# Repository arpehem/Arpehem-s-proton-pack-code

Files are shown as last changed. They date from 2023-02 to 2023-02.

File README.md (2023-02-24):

# Arpehem-s-proton-pack-code
This is the code to use if you realyzed you bought a **common cathode bargraph** or only have access to this model.
This code is designed to be used with **2 Arduino nanos** or your favorite boards that have at least as many i/o ports and handles Arduino in order to minimyze the amount of wires running from the wand to the pack and has a unique smoke purge seuqence and design as well as all the bargraph animations.

These files and instructions are compatible with the Q-Pack.

Check out this link to see it in action:
https://youtu.be/VGt3vFmbnvs

Features:
- Common cathode bargraph full animations
- aRGB 4x5mm aRGB wand tip LED lights
- Functional top and front wand knobs
- Music mode and volume control on the wand
- Bargraph volume display
- Full pack aRGB controled
- New N-filter realistic smoke purge system
- DYI smoker build
- Compatible with pre-built smoker
- Uses DFplayer mini
- Customisable sound amplification
- Aviation connector adaptor for the wand handle
- Bluetooth (depending on the amp)

Upcomming updates:
- Firing tail sound 
- Game modes
- Top knob functionality

Which code to use?
- Use Neutrino wand code for the nano placed in the wand.
- Use Cyclotron_single_lights on your pack nano if you have single aRGB cyclotron lights.
- Use Cyclotron if you have 7 LED aRGB pucks for your cyclotron. Know that this code may be outdated, only single lights version is being worked on trough the end of this project as it was a design decision change but I wanted to include the option to use what you have/want and update the code yourself. (I was almost done I beleive and it is functional)

How it works:
Main power switch will turn on the slo-blo light at all time to indicate that the pack powered.
There is a sequence to turn the pack on that has to be respected. First step is to activate the particule accelerator controller (wand) on, flip on the wand light switch. That turns on the wand top light on indicating it's under tension. Second we flip the boot switch on which boots the pack and the rest of the wand. The pack goes trough it's boot animation sequence, the bargraph lights up by doing it's boot animation, then falls into it's loop at the same time as the pack starts and the 2 white hat lights on the wand start flashing. The third switch is to turn the smoke effect on and off as it is not allowed in all conventions.

Firing is fairly straight forward, just press the fire pin button. When firing, the 4 wand tip lights are controlled by a random function made to have white flashes, most of the time orange lights with hints of blues. The orange hat light also lights up when firing. At any time while firing, pressing the vent pin button will call a vent function that will pause the flashing light animation on the wand whyle the cyclotron is purging. If you installed a smoker, when you vent before entering the overhead sequence, there will be a breif lag (half a second) in between the command and the action to allow the smoker to build up a bit of smoke for a better effect. Shooting will make the cyclotron go faster untill it reaches the ovearheting sequence.

If you shoot long enough, you will enter the overheating sequence that will change the bargraph animation, sound the allarm, make the 3rd wand top light flash, flash all 4 cyclotron lights at the same time and alter LEDs on the Power cell. If you let go of the firing button or if you press the vent button in that 'mode', it will engage the vent sequence that will change the bargraph animation, light up the N-Filter, activate the purge fan propelling the smoke out of the N-filter and return to normal cycle loop afterwards.

If you keep shooting, you will enter the overheat sequence. The bargraph animation will change and the pack will force vent, doing all the thing normal venting would do but insttead of going back to the normal cycle sequence, it will force shutdown. This is by design. If this happens to you, you have to turn off both the boot and the wand pin switches and switch them back on in the propper order for it to restart. Only shutting down the pack switch on the wand will not allow to reboot, the user has to complete the shutdown sequence by turning everything off before turning it back on to exit the overheated mode.

Controlling the music and the volume is done with the front knob which is attached to the rotary encoder. Pressing it once will put it in volume mode which will display it's value on the bargraph. Raisin the volume will raise the bargraph value and vice versa. Clicking it once more will bring it back to normal mode. Double clicking the rotary encoder will start the music and holding it down will skipp to the next song. Clicking it twice again will bring it back in normal pack mode.

Required components:
-  Audio option 1 (speakers and sub watts have to be a bit more than the chosen amp output to avoid any problems):
- - 1 x Subwoofer the size that fits your motherboard speaker hole.
- - 2 x 3" car speaker 
- - 1 x amp with 2 speaker channels and 1 sub channel
- Audio option 2 (speaker wattage has to be a bit more than the chosen amp output to avoid any problems):
- - 1 x Speaker that fits your motherboard speaker hole.
- - 1 x amp 1 channel (mono)
- DIY Smoker:
- - 1 x 510 to EGO adapter (optional but way easier to use)
- - 1 x 12a 100W buck converter
- - 3 X 20a relay
- - 1 x 0.8 omh Vape tank and coil
- - 1 x 50mm 230mah blower fan
- - 3d printer
- - 3" of 1/4" plastic tubing that can be found in hardware stores
- - 3/16" A/C air conditioner filter sheet

Wand and pack:
- 1 x 2 way rotary switch (https://amzn.to/40L4XQX)
- 4 x 41x33mm Aluminum LED Flashlight Reflector Condenser Cup Cap
- 4 x 8mm aRGB LED (5mm could fit too)
- 1 x 6000 Mah battery pack (Recommend Talentcell)
- 3 x 20a relay
- 1 x 5V 40mm fan
- 2 x 3a buck converter
- 1 x 360 Degree Rotary Encoder Module
- 2 x Arduino nano (Or other boards with as many I/O ports that handles Arduino)
- 1 x Adafruit 16x8 LED Matrix Driver Backpack - HT16K33 Breakout
- 1 x Common cathode 28 segment LED bargraph
- 2 x Adafruit NeoPixel Stick for Arduino- 8 x WS2812
- 4 x 5mm aRGB LED
- 2 x 7mm Momentary (OFF-ON) Push Button Micro Switch
- 3 x 2 Position 3 Pins Mini Toggle Switch
- 1 x SS-10-23NP-L-E Rotary switch (https://bit.ly/3HUpoSU)
- 3 x 5mm white LED
- 1 x 3mm red LED
- 1 x 5mm yellow LED
- 1 x 5V white LED strip (about a foot)
- 10 x 1k omh resistances
- 2 x NPN transistor (2N2222)
- 1 x 4-PIN aviation connector (Optional)
- 1 x DF player mini

Here is a shopping list of the parts I found on Amazon:
https://www.amazon.ca/hz/wishlist/ls/2MNKQJ50DXHUB?ref_=wl_fv_le

Pinout:

Wand: 
- D2 Boot pin (wand switch 2)
- D3 Light switch (wand switch 1)
- D4 Smoke switch (wand switch 3)
- D5 Fire pin (fire button)
- D6 Vent pin (vent button)
- D7 Btn pin (Rotary encoder btn pin)
- D8 DT  (Rotary encoder data pin)
- D9 CLK  (Rotary encoder clock pin)
- D10 Cannon LED aRGB (Wand tip LED)
- D11 Fire light (wand tip orange light)
- D12
- D13 Rotary switch 1 (top knob rotary switch output 1)
- A0 Slo-blo LED (wand red light)
- A1 Wand white flashing hat light 1 (Wand top light large)
- A2 Wand white neon hat light (Wand top light small)
- A3 Wand white flashing hat light 2 (Wand top light large)
- A4 HT16K33 matrix SDA
- A5 HT16K33 matrix SCL
- A6 Rotary switch 2 (top knob rotary switch output 2)
- A7 Rotary switch 3 (top knob rotary switch output 3)

Pack:
- D2 Cyclotron aRGB data
- D3 Powercell aRGB data
- D4 Purge pin (Purge relay)
- D5 Smoke pin (smoke relay)
- D10 DFplayer mini RX
- D11 DFplayer mini TX

Instructions:
I will skipp trough: 'connect positive to the positive contact and negative to the negative contact. Remember that every negative needs to go to the main power switch before the power supply. Do not power devices trough the arduino 5V outputs, use buck converters to modulate the 12V signal to a 5V one. Audio needs to be on it's own buck converter to avoid interference BUT the amp, power that one 12V directly from the power source.

- **Wand connector:** Print the plug file. This is a replacement end cap for the wand handle allowing you to use a 4 pin aviation connector to easily disconnect the want from the pack.
- **Prepping the inputs:**
Every button or switch input need to go to the i/o ports it's assigned to which needs to have a 1k omh resistance running to the ground each. This is to limit interference and ghost inputs. (not a pun) An easy way to do this is to use dupont connectors in which you brace the input wire with the 1k omh resistor. Once everything connected, weld all resistances together on a ground.
- **Power and communication:** Start by running power from the main power switch (2 way rotary switch) connected to a buck converter that lowers the 12V to 5V to the 2 arduinos separately. Do not use 5V directly from the battery pack, it causes issues. Connect the first arduino's RX to the second one's TX and the first one's TX to the second one's RX. Basically, connect them backwards to one another. Now the wand 'speaks' to the pack.
- **Wand tip:**
Glue 4x5mm aRGB LEDs next to one another so that it fits where you want it to go in the barrel. Daisy chain them and connect the first one's data input to wand D10. (Remember, to connect individual aRGB LEDs, you need to connect i'ts data out to the next one's data in)
- **Power cell:**
Sawder the output contacts of the first bar onto the input contacts of the second one to make a 16 bit led bar. Connect the first bar data input to pack D3.
- **Cyclotron:**
Glue in the 8mm led INSIDE the flashlight reflector or trough them if you got 5mm aRGB LEDs instead. Connect the first one's data pin to pack D2.
- **DIY Smoker:**
We're going to push air in the vape's air inlet instead of pulling it out. Use a dremel to marry the blower fan to the side of the vape tank. Use a tie-wrap to secure the blower fan onto the base of the vape tank alligned with the vape tank's air intake. Dril a hole in your 510 to EGO adapter's base and use it to sawder in a wire to ground. Sawder directly onto the midle contact for the positive contact. Screw in the vape tank adaptor and connect it to the high power buck converter. Connect the high power buck converter to a 20a relay. That relay is controlled by the smoke pin Arduino output. The white 5v LED strip is to be connected to it's own relay and so does the 40mm purge fan. Theire individual relays are activated by a third relay that is driven by the smoke purge pin.

You will need to print these files for the purge tank:
https://www.thingiverse.com/thing:5848057

**You'll need these pieces:**
- 45_intake_2
- 90_angle
- Vent_cup
- 90_intake_2
- and a tip diffuser of your liking listed in the files.

You have an array of tips to choose, I prefer the 1 row 1 tip diffuser.
Print the smoker files.
Glue on the tip on the straight end of the 90_intake_2 piece. Glue the 45_intake_2 in the side hole of the vent_cup. Glue to 90_intake_2 to the end of the 45_intake_2 end in the vent_cup. Use 1/4" plastic tubing to connect the intake to the 90_angle and then to then output of the vape tank.
The parts are jointed by 1/4" plastic tubing.
Cut a piece of 3/16" air filter a bit larger than the 40mm fan. Place the air filter on the vaent cup round hole and crew the 40mm in with 4 M3 screws pushing trough the filter. This will create enough air resistance so that the smoke stays in the smoker but not enough to keep the fan from blowing air trough it. You're going to need to tweak the buck converter's voltage for your vape machine to produce a light but thick smoke that produces the wanted effect. You should now have a cup fitting to be glued inside the proton pack, alligned with the N-filter that has a fin on it's back and a tube driving the smoke from the smoker output to about halfway into the N-filter. **Glue down the assembly only after installing N-filter meshes and lights.** You will not be able to remove the N-filter purge container. If the purge fan is not spinning fast enough, change it's relay power supply to be on a different buck converter. It means that the N-filter lights are drawing too much power so you need a different power moduluator (buck in our instance). 
- **Bought smoker**:
Follow the smoker's instructions on how to power it but, do it trough the smoker relay so that it's activated by our code. There is no special need for the smoker in order for the purge function to work properlly other than to spew out smoke when powered.If the purge fan is not spinning fast enough, change it's relay power supply to be on a different buck converter. It means that the N-filter lights are drawing too much power so you need a different power moduluator (buck in our instance).
- **Connecting a relay to arduino:**
In order for the arduino to be able to drive a relay, we're going to need to use transistors attached to resistances. Sawder a 1k resistance to the middle prone of a PNP 2N2222 transistor. Sawder one of the 2 side ones to the negative of the power supply and the other end to the relay. Whatever is driven by the relay needs to be connected to the ground trough the relay and directly to the negative side of the power supply/main power switch. Connect the resistance that is sawdered onto the middle prone of the transistr to the Arduino board. Do this for the smoker pin and the purge pin relays. A relay has 2 emmiter prones, one normally opened, one normally closed, you want your signal to run trough the normally opened one. Normally opened mean that it does not normally convey signal, the circuit is opened (as in there's a break in the circuit) it needs an interraction to close the circuit and therefore transmit the signal/voltage.
- **Audio:**
Connect the speaker(s) to the amp. Power the amp straight from the powercell. Don't use power converters as it will induce interference in the audio signal. Connect the amp's ground the main power switch (or power if you decided to control power by the positive). Connect the DFplayer mini outputs to the amp's input. Unpack the MP3.rar in a folder called MP3 on a SD card and insert it in de DFplayer mini.
- **Front volume/music knob:**
Desawder the rotary encoder from it's board without damaging either parts. Use 1" wires sawdered to each leg of the rotary encoder and sawder those onto their respective places on the removed board. There you have it: a rotary encoder that fits in the front knob position. Carefull not to drill the hole it goes into too close to the Clippard valve as the front knob will need to have clearance to be pushed and turned. In order to glue the front knob on the rotary encoder correctly, I recommend using a gauge to space it from the main wand box when installing to leave clearance for a click and if you are using an alluminum knob, I used a long set screw from the inside of it to create an inner spacer.
- **Top knob:**
Glue a M3 nut on the top the 3 position rotary switch selector. Run a long M3 screw in the tob knob and glue them together. Install top knob in it's place and screw in the nut on the top of the rotary switch to it. Now that the top knob is attached to the rotary switch, make sure the know is in the correct place and glue the 3 position switch to the inside of the wand box. You can unscrew and screw it back (for painting) if you are carefull. Make sure to not apply too much force to the switch when screwing the top knob in and out as it will easily break (I recommend ordering 5 to have spares).
- **Main power switch (optional):**
Dril a hole where the crank generator crank goes. Use the 2 way oven style switch and glue it inside the pack trough the hole so that you can fit/glue the crank on it's stub. Use this switch between every ground and the power source ground.

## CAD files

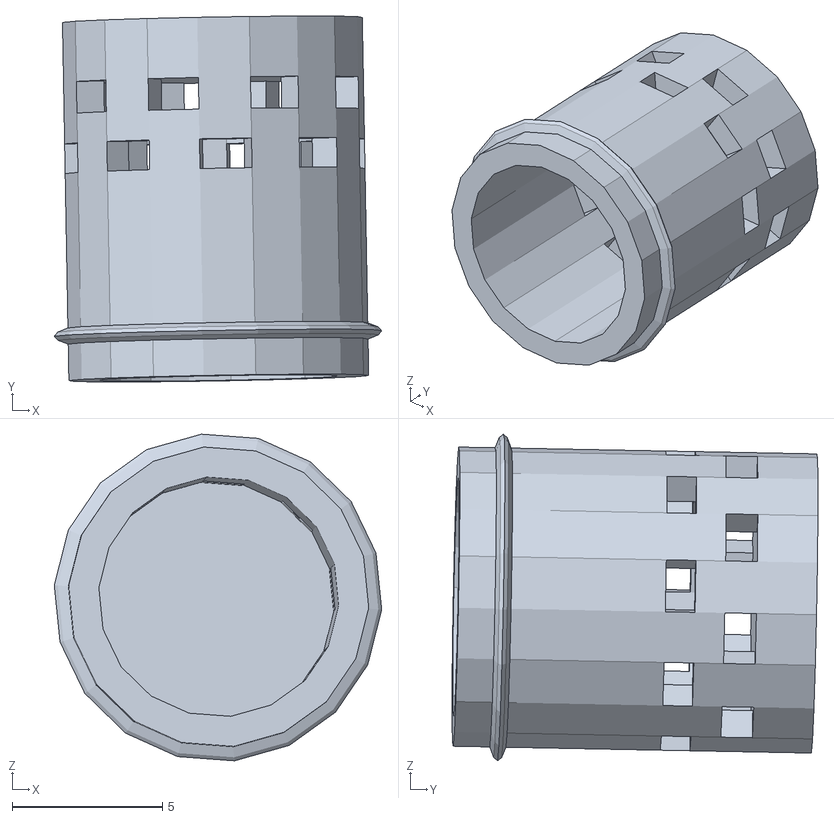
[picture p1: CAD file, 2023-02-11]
2 row.stl
10.9 x 12.2 x 10.9

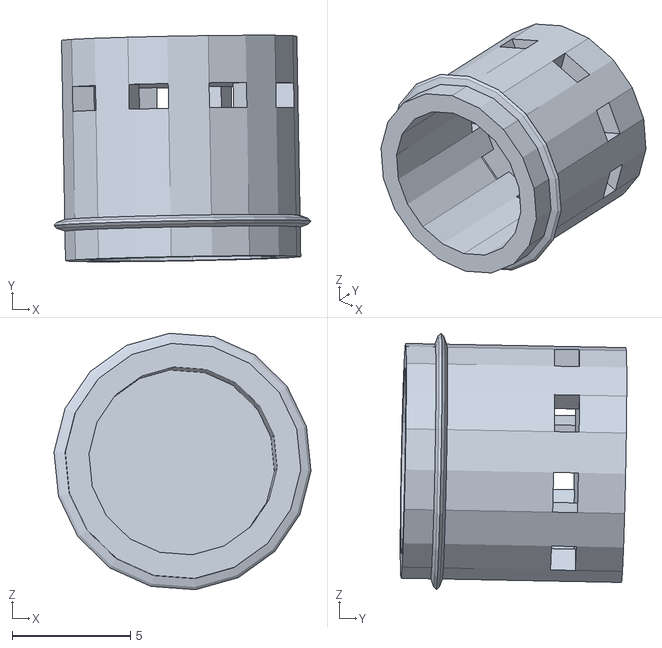
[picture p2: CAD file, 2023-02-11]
1 row.stl
10.9 x 9.60 x 10.9

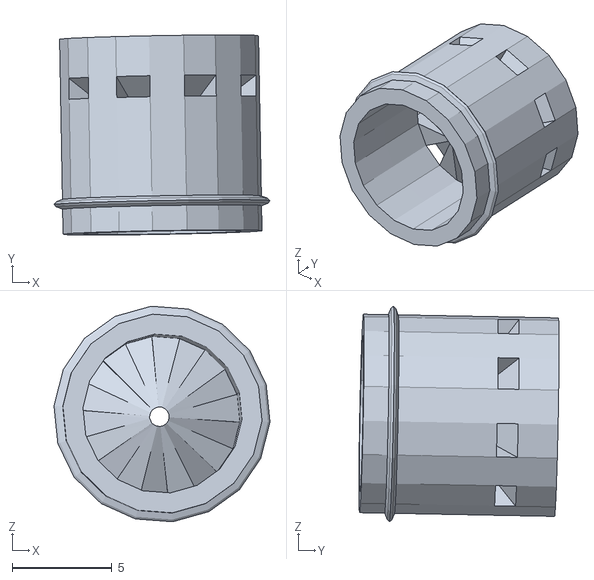
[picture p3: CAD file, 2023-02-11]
1 row 1 spray1.stl
10.8 x 10.0 x 10.8

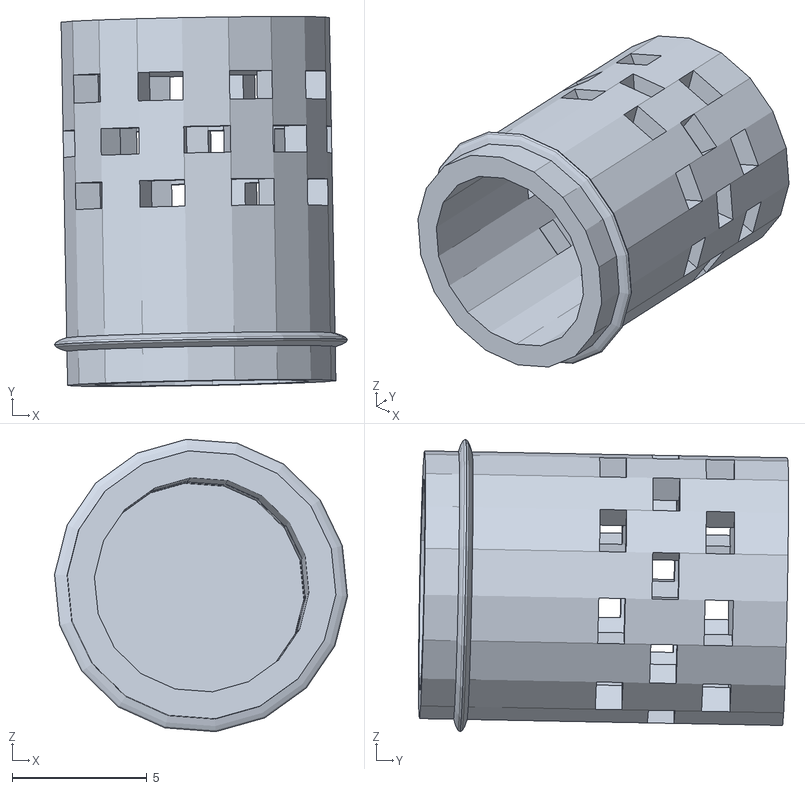
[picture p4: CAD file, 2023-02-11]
3 row.stl
10.9 x 13.8 x 10.9

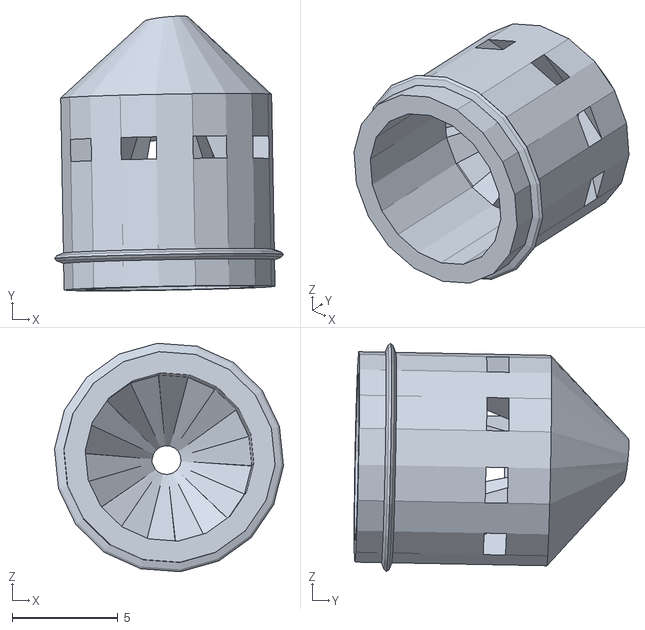
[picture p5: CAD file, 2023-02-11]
1 row 1 tip.stl
10.8 x 13.0 x 10.8

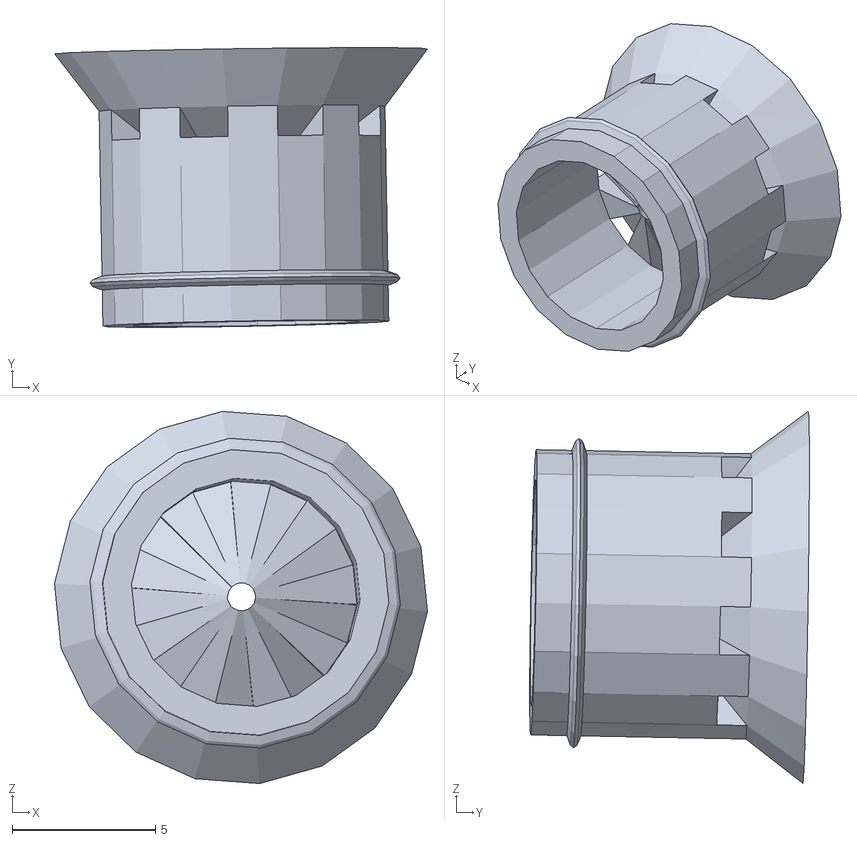
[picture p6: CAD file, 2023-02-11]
1 row 1 spray3.stl
13.0 x 9.75 x 13.0

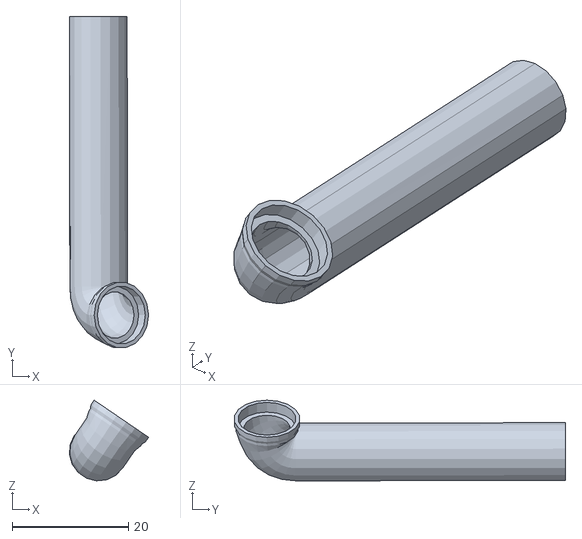
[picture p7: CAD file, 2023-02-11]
90 intake2.stl
13.6 x 57.0 x 13.9

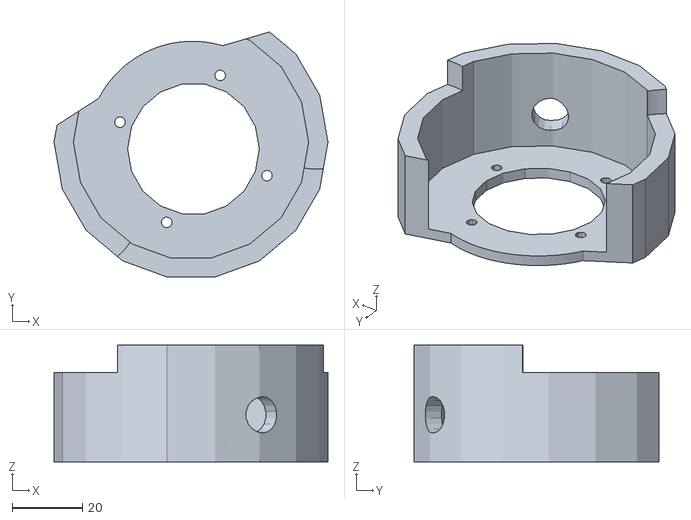
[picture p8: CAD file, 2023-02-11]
Vent_cup.stl
77.8 x 69.6 x 33.2

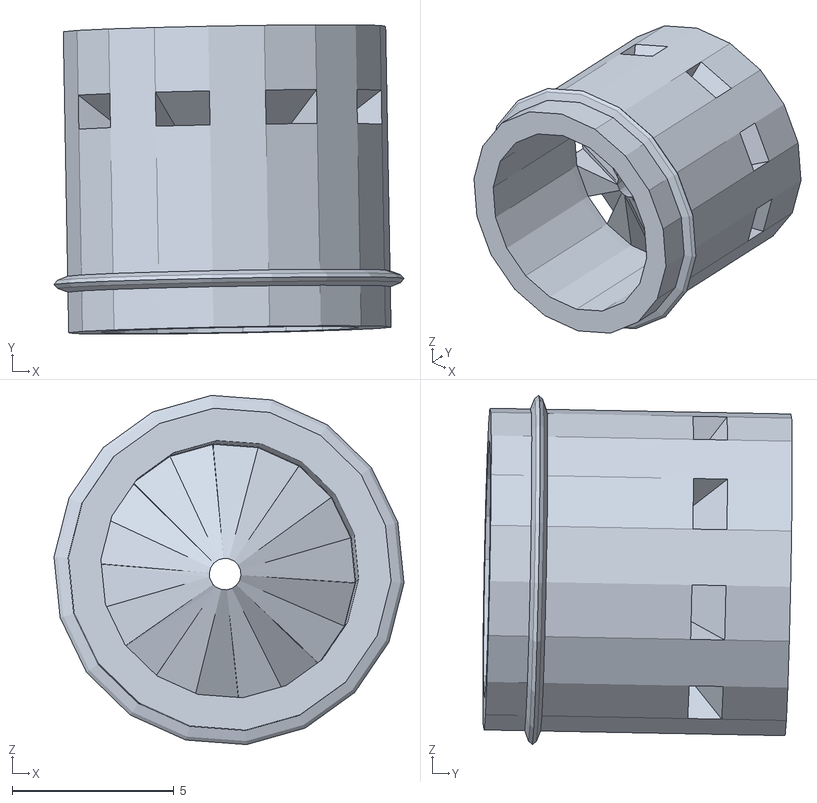
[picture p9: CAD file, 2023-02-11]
1 row 1 spray2.stl
10.8 x 9.57 x 10.8

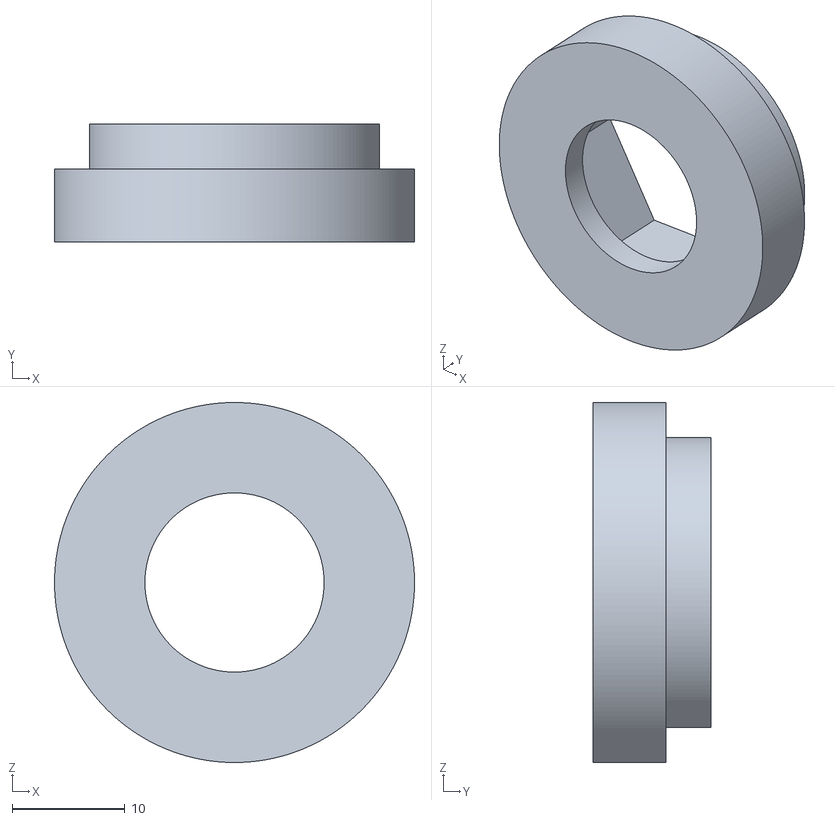
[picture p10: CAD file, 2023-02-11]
plug01.stl
32.0 x 10.5 x 32.0

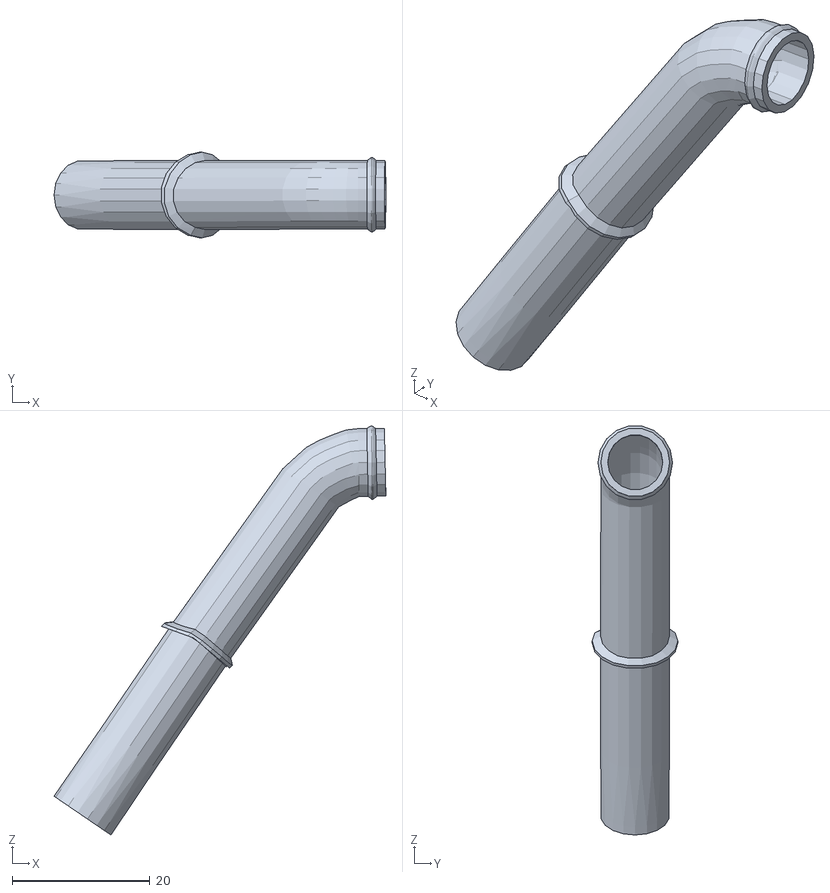
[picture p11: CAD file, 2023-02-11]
45 intake2.stl
48.2 x 12.5 x 59.4

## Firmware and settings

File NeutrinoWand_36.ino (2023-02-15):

// This code has initially been created entirelly by Arpehem and is free to be used, modified or updated by anyone as long as this credit remains.
// This code is compatible with a common cathode bargraph only.

#include <FireTimer.h>
#include <DFPlayerMini_Fast.h>
#include <SoftwareSerial.h>
#include <BfButton.h>
#include <BfButtonManager.h>
#include <HT16K33.h>
#include <FastLED.h>
# define NUM_LEDS 4
# define NUM_STRIPS 1
# define WAND_LEDS 4
#define WAND_LED_PIN 10

HT16K33 matrix = HT16K33();
char Volume=20;
int bargraph=0;
int BGadress[4]={1,4,8,2};
int demo;
char S = 35;
int i;
int overloadtime=5000;
int J=0;
int K=0;
int shooting = 0;
enum currentstate{on,off,boot,cycle,fire,overloading,overload,overheat,music,volumep,ventp}state;
unsigned long myWandTime;
unsigned long previousWandTime = 0;
unsigned long previousLightTime=0;
unsigned long previousAlarmTime=0;
unsigned long previousShootLight=0;
unsigned long ShootingTime = 0;
unsigned long PreviousShootingTime = 0;
bool isFire = false;
bool wasFire =false;
bool booted=false;
bool issmoke=false;
bool up = true;
bool lightcycle =true;
bool alarmlighton =false;
int firepin = 5;
int bootpin = 2;
int ventpin = 6;
int smokeswitch = 4;
int lightswitch =3;
int rot1 = 13;
int firelight = 11;
int powerlight = 12;


CRGB wand_leds[WAND_LEDS];
CLEDController *controllers[NUM_STRIPS];


int btnPin=7;
int DT=8;
int CLK=9;
BfButton btn(BfButton::STANDALONE_DIGITAL,btnPin,true,LOW);

int counter = 0;
int angle = 0;
int aState;
int aLastState;

void pressHandler (BfButton *btn, BfButton::press_pattern_t pattern){  //////////////////////////////////ROT Handler///////////////////////////////////////
  switch (pattern) {
    case BfButton::SINGLE_PRESS:
   // myMP3.playAdvertisement(8);
    if (state==volumep){
      state=cycle;
     Serial.write('c');
      delay(50);
    }
    else{
      Serial.write('V');
     delay(50);
      state=volumep;
          matrix.clear();
    i=Volume;
    angle=Volume;
    counter=Volume;
    cycle_switch();
  matrix.write();
    }
      break;
      
    case BfButton::DOUBLE_PRESS:
   // myMP3.playAdvertisement(8); 
         if (state==music){
      state=cycle;
Serial.write('m');
delay(50);
    }
    else{
      state=music;
Serial.write('m');
delay(50);
    }
      break;
      
    case BfButton::LONG_PRESS:
    Serial.write('n');
delay(50);
    
      break;
  }
}




void setup() {       ///////////////////////////SETUP///////////////////////////////////
Serial.begin(9600);
//mySerial.begin(9600);
//myMP3.begin(mySerial, true);
pinMode(CLK, INPUT_PULLUP);
pinMode(DT, INPUT_PULLUP);
aLastState = digitalRead(CLK);
//myMP3.volume(Volume);
  //Button settings
  btn.onPress(pressHandler)
  .onDoublePress(pressHandler) // default timeout
  .onPressFor(pressHandler, 1000); // custom timeout for 1 second

  matrix.init(0x70);   // start the matrix on I2C address 0x70
  delay(1500);
state= off;
pinMode(firepin, INPUT);
pinMode(bootpin, INPUT);
pinMode(ventpin, INPUT);
pinMode(smokeswitch, INPUT);
pinMode (lightswitch, INPUT);
pinMode (rot1, INPUT);
pinMode (11, OUTPUT);
pinMode (12, OUTPUT);
//analog i/o
pinMode (A0, OUTPUT);
pinMode (A1, OUTPUT);
pinMode (A2, OUTPUT);
pinMode (A3, OUTPUT);
pinMode (A6, INPUT);
pinMode (A7, INPUT);

controllers[0] = &FastLED.addLeds<WS2812, WAND_LED_PIN, RGB>(wand_leds, WAND_LEDS); // Assign wand LED to controller 0
  FastLED.setMaxPowerInVoltsAndMilliamps(5,500);

analogWrite(A0, 175); // light slo-blo as pack status light
FastLED.setBrightness(255);
FastLED.clear();
FastLED.show(); 
}
void loop() {                  //////////////////////////////////////LOOP//////////////////////////////////////

myWandTime=millis();  // Records current time

if (myWandTime>previousShootLight+25&&isFire==true){
  shooting++;
  if (shooting>3){
    shooting=0;
  }
     FastLED.clear();
//wand_leds[min(shooting+1,3)] = CRGB(150,30,255);
wand_leds[random(0,3)] = CRGB(75,30,255);
wand_leds[random(0,3)] = CRGB(200,30,30);
wand_leds[random(0,3)] = CRGB(150,30,0);
wand_leds[random(0,3)] = CRGB(150,30,0);
wand_leds[random(0,3)] = CRGB(150,30,0);
wand_leds[max(shooting-1,0)] = CRGB(150,30,0);
wand_leds[shooting] = CRGB(254,100,0);
  FastLED.show(); 
  previousShootLight=millis();
}
if (digitalRead(smokeswitch)==true&&issmoke==false){
Serial.write('y');
issmoke=true;
}
if (digitalRead(smokeswitch)==false&&issmoke==true){
Serial.write('x');
issmoke=false;
}
if (digitalRead(lightswitch)==true&&state==off&&digitalRead(bootpin)==false){
state=on;
analogWrite(A7,130);
}
if (digitalRead(lightswitch)==false&&state!=off){
state=off;

}
if(state==off||state==overload){
analogWrite(A1,0);
analogWrite(A2,0);
analogWrite(A3,0);
analogWrite(A6,0);
analogWrite(A7,0);
}


if(myWandTime>previousLightTime+600&&digitalRead(lightswitch)==true&&lightcycle==false&&booted==true){
  analogWrite(A1,130);
  analogWrite(A3,0);
  lightcycle=true;
  previousLightTime=millis();
}
if(myWandTime>previousLightTime+600&&digitalRead(lightswitch)==true&&lightcycle==true&&booted==true){
  analogWrite(A3,130);
  analogWrite(A1,0);
  lightcycle=false;
  previousLightTime=millis();
}

  btn.read();
  
  aState = digitalRead(CLK);

                                  //////////////////////////Encoder rotation tracking////////////////////////////////
  if (aState != aLastState){     
     if (digitalRead(DT) != aState) { 
       counter ++;
       angle ++;
      //        counter=min(counter,29);
     //  angle=min(angle,29);
       
     }
     else {
       counter--;
       angle --;
      // counter=max(counter,0);
      // angle=max(angle,0);
     }
     if (counter >=28 ) {
       counter =28;
     }
     if (counter <=-0 ) {
       counter =-0;
     }
    // Serial.println(counter); 
  }   
  aLastState = aState;
if (state==volumep&&Volume!=counter){
    matrix.clear();
    Volume=counter;
    Volume=min(Volume,28);
    Volume=max(Volume,0);
    i=Volume;
    Serial.write(Volume);
    cycle_switch();
  matrix.write();
  
 // myMP3.volume(Volume); 
 // delay(50);
 //   Serial.begin(9600);
}
  
if(digitalRead(ventpin)==true&&state==fire||digitalRead(ventpin)==true&&state==overheat||digitalRead(ventpin)==true&&state==overloading){ ///////////////////////////// if pack is shooting and the vent pin is pressed before the forced venting, calls venting without shuting down/////////////////////////////
  vent();
  state=cycle;
  Serial.write('c');
  delay(50);
  loopsound(2);
  i=0;
  J=0;
  S=35;
  Serial.write(S);
}

if(state!=off&&state!=on&&state!=cycle&&state!=overload&&state!=overloading&&state!=overheat&&state!=music&&state!=volumep&&state!=boot&&isFire==false){
  state=cycle;
    Serial.write('c');
  delay(50);
  S=35;
  Serial.write(S);
 }
if(state==music && myWandTime > previousWandTime+35){
  cyclesequence();
}
if(state==overloading&&isFire==false||state==overheat&&isFire==false){
  vent();
  state=cycle;
    Serial.write('c');
  delay(50);
  S=35;
  Serial.write(S);
}

//if(digitalRead(bootpin)==false){ //if switch is off, state is off
//  state=off;

//}
isFire=digitalRead(firepin); // Reads fire button input and sets isFire accordignly
//if(state==off){
//  isFire=false;
//}

if(state!=boot&&state!=on&&digitalRead(bootpin)==false&&booted==true){ ///////////////////////////////////// if state is not boot state, pack is booted and switch is off, calls shutdown////////////////////////////////////
  state=off;
Serial.write("f");
delay(50);
shutdownsequence();
  
  booted=false;
  state=off;
  matrix.clear();
  matrix.write();
  i=0;
}
if(state==on&&digitalRead(bootpin)==true&&booted==false){ //////////////////////////////////// if pack is not booted and switch is on, calls boot//////////////////////////////////////
  state=boot;
  Serial.write("b");
delay(50);
}
if(state==off&&digitalRead(bootpin)==true&&booted==true){ /////////////////////////////////////// if pack is off but still booted and switch is on, calls shutdown/////////////////////////////////
  state=off;
 // shutdownoverloadsequence();
 shutdownsequence();
Serial.write("f");
delay(50);
}

  if(state==boot){  /////////////////////////////// Check for boot state and calls bootsequence/////////////////////////////////////////////////

  playsound(1);
  bootsequence();
  
  }
if (myWandTime > previousAlarmTime+200&&state==overloading||myWandTime > previousAlarmTime+200&&state==overheat){ // Check for cycle , calls cyclesequence
  alarmlight();
}
if (myWandTime > previousWandTime+28 && isFire == false && booted == true&&state==cycle){ // Check for cycle , calls cyclesequence
  cyclesequence();
}
if (myWandTime > previousWandTime+S && isFire == true && booted == true&&S>1){ // Check for fire , calls firesequence
firesequence();
}
if (myWandTime > previousWandTime+35 && isFire == true && booted == true&&S==1&&J<300 && state != off && state != overload&&state!=ventp){ // Check for fire , calls overheat sequence


  cycleoverheatsequence();
}
if (myWandTime > previousWandTime+35 && isFire == true && booted == true&&state!=ventp&&S==1&&J==300&&K<125&& state != off){ // Check for fire , calls overload/vent sequence


  overloadsequence();
}
}
void demo_cycle (){            //////////////////////////////// Demo of bargraph animations without timing or trigger//////////////////////////////////////////////
    demo++;
  for (int i=0; i<2;i++){
    cyclesequence();
  }   
    for (int i=0; i<10;i++){
    firesequence();
  } 
    for (int i=0; i<20;i++){
    cycleoverheatsequence();
  }  
  overloadsequence();

}
void alarmlight(){
  switch (alarmlighton) {
  case true:
        analogWrite(A2, 0);
    alarmlighton=false;
    previousAlarmTime=millis();  
    break;
  case false:
    analogWrite(A2, 130);
    alarmlighton=true;
    previousAlarmTime=millis();  
    break;
  default:
    // statements
    break;

}
}
void playsound(int sound){
//    mySerial.begin(9600);
 // delay(50);
 // myMP3.play(sound); 
 // delay(50);
 //   Serial.begin(9600);
 
}
void loopsound(int sound){
 //   mySerial.begin(9600);
//  delay(50);
//  myMP3.loop(sound); 
//  delay(50);
//    Serial.begin(9600);
  
}
void bootsequence(){  // Boot Sequence
  for(int i=0&&Serial.write("b");i<28;i++){
    matrix.clear();
    cycle_boot(i);
    matrix.write();
    delay(125);
    }
  for(int i=28;i<57;i++){
    matrix.clear();
    cycle_boot(i);
    matrix.write();
    delay(25);
  }
  booted=true;
  loopsound(2);
  state=cycle;
      Serial.write('c');
    delay(50);
  }
void shutdownsequence(){ 
  Serial.write("f");
  
  playsound(10);
  analogWrite(A1,0);
  analogWrite(A3,0);
  for(int i=28;i<57;i++){
    matrix.clear();
    cycle_boot(i);
    matrix.write();
    delay(75);
  }
  state=off;
  digitalWrite(firelight,LOW);
  
  delay(50);
  booted=false;
  matrix.clear();
  matrix.write();
  i=0;
  previousWandTime=myWandTime;
  
}
void shutdownoverloadsequence(){  
Serial.write("f");
playsound(10);  
    for(int i=28;i<57;i++){
    matrix.clear();
    cycle_boot(i);
    matrix.write();
    delay(25);
  }
  state=overload;
  
 
  delay(50);
  booted=false;
  i=0;
  matrix.clear();
  matrix.write();
  
  
  previousWandTime=myWandTime;
}
void cyclesequence(){  // Normal cycle sequence
    if(wasFire==true){
    wasFire=false;
    FastLED.clear();
    FastLED.show(); 
    i=0;
    state=cycle;
    S=35;
    Serial.write(S);
    Serial.write('c');
    delay(50);
    digitalWrite(firelight,LOW);
    analogWrite(A2,0);
  }
  if(state!=cycle&&state!=music&&state!=volumep){
    loopsound(2);
    state=cycle;
        Serial.write('c');
    delay(50);
    
    
  }
  if (i>28){
    i=28;
  }
  if (i==28){
    up=false;
  }
  if (i==0){
    up=true;
  }
  if(up == true){
    i++;
  }
    if(up==false){
    i--;
  }
matrix.clear();
cycle_switch();
matrix.write();
previousWandTime=myWandTime;
}
void firesequence(){  // Fire suquence
  if (wasFire==false){
  wasFire=true;
  Serial.write('s');
  delay(50);
  loopsound(11);
digitalWrite(firelight,HIGH);
 }

 if (state!=fire){
    i=0;
  state=fire;
  J=0;
 }
 ShootingTime=millis();
if(ShootingTime>PreviousShootingTime+500){
  S--;
  PreviousShootingTime=millis();
Serial.write(S);

}
 if (i>19){
   i=0;
  }
  i++;
matrix.clear();
fire_switch();
matrix.write();
previousWandTime=myWandTime;
}
void vent(){
  state=ventp;
  FastLED.clear(); 
  FastLED.show(); 
  analogWrite(A2,0);
       Serial.write('v');
       digitalWrite(firelight,LOW);
    delay(50);
  playsound(9);
  wasFire=false;
  for (int i=24; i<34;i++){
  matrix.clear();
cycle_overload(i);
matrix.write();
delay(35);
}


matrix.clear();
cycle_overload(35);
matrix.write();
delay(3000);
state=off;
i=0;
previousWandTime=myWandTime;
}

void overloadsequence(){ // Overheat/vent sequence
 if(state==overheat){
  state=overloading;
 i=0;
 K=0;
 up=true;
     Serial.write('o');
    delay(50);
 }
K++;

   switch (K) {
  case 1:
    up=true;
    break;
  case 35:
    up=false;
    break;
  case 45:
    up=true;
    break;
  case 55:
    up=false;
    break;
  case 65:
    up=true;
    break;
  case 75:
    up=false;
    break;
  case 85:
    up=true;
    break;
  case 95:
    up=false;
    break;
  case 105:
    up=true;
    break;
  case 115:
    up=false;
    break;
  case 124:
  vent();
  analogWrite(A1,0);
analogWrite(A2,0);
analogWrite(A3,0);
analogWrite(A6,0);
analogWrite(A7,0);
shutdownsequence();
state=overload;
isFire=false;
wasFire=false;

      break;
}
   
if(up==true){
  i++;
}
if(up==false){
  i--;
}
if(K<124){
    matrix.clear();
cycle_overload(i);
matrix.write();
previousWandTime=myWandTime;

}
if(K==124){
  i=0;
  J=0;
  K=0;
  S=35;
  Serial.write(S);
}
}
void cycleoverheatsequence(){ // Overload (warning) sequence
   if(state==fire){
  state=overheat;
  i=0;
//J=0;
loopsound(16);
     Serial.write('h');
    delay(50);
 }
i++;
J++;
  matrix.clear();
  cycle_overheat();
  matrix.write();

if (i>4){
  i=0;
}
previousWandTime=myWandTime;
}
void cycle_boot(int boot){
  switch (boot) {
  case 1:
    matrix.setRow(6, 2);
    break;
  case 2:
    matrix.setRow(6, 10);
    break;
  case 3:
    matrix.setRow(6, 14);
    break;
  case 4:
    matrix.setRow(6, 15);
    break;
  case 5:
    matrix.setRow(5, 2);
    matrix.setRow(6, 15);
    break;
  case 6:
    matrix.setRow(5, 10);
    matrix.setRow(6, 15);
    break;
  case 7:
    matrix.setRow(5, 14);
    matrix.setRow(6, 15);
    break;
  case 8:
    matrix.setRow(5, 15);
    matrix.setRow(6, 15);
    break;
  case 9:
    matrix.setRow(4, 2);
    matrix.setRow(5, 15);
    matrix.setRow(6, 15);
    break;
  case 10:
    matrix.setRow(4, 10);
    matrix.setRow(5, 15);
    matrix.setRow(6, 15);
    break;
  case 11:
    matrix.setRow(4, 14);
    matrix.setRow(5, 15);
    matrix.setRow(6, 15);
    break;
  case 12:
    matrix.setRow(4, 15);
    matrix.setRow(5, 15);
    matrix.setRow(6, 15);
    break;
  case 13:
    matrix.setRow(3, 2);
    matrix.setRow(4, 15);
    matrix.setRow(5, 15);
    matrix.setRow(6, 15);
    break;
  case 14:
    matrix.setRow(3, 10);
    matrix.setRow(4, 15);
    matrix.setRow(5, 15);
    matrix.setRow(6, 15);
    break;
  case 15:
    matrix.setRow(3, 14);
    matrix.setRow(4, 15);
    matrix.setRow(5, 15);
    matrix.setRow(6, 15);
    break;
  case 16:
    matrix.setRow(3, 15);
    matrix.setRow(4, 15);
    matrix.setRow(5, 15);
    matrix.setRow(6, 15);
    break;
  case 17:
        matrix.setRow(2, 2);
    matrix.setRow(3, 15);
    matrix.setRow(4, 15);
    matrix.setRow(5, 15);
    matrix.setRow(6, 15);
    break;
  case 18:
        matrix.setRow(2, 10);
    matrix.setRow(3, 15);
    matrix.setRow(4, 15);
    matrix.setRow(5, 15);
    matrix.setRow(6, 15);
    break;
  case 19:
        matrix.setRow(2, 14);
    matrix.setRow(3, 15);
    matrix.setRow(4, 15);
    matrix.setRow(5, 15);
    matrix.setRow(6, 15);
    break;
  case 20:
    matrix.setRow(2, 15);
    matrix.setRow(3, 15);
    matrix.setRow(4, 15);
    matrix.setRow(5, 15);
    matrix.setRow(6, 15);
    break;
  case 21:
    matrix.setRow(1, 2);
    matrix.setRow(2, 15);
    matrix.setRow(3, 15);
    matrix.setRow(4, 15);
    matrix.setRow(5, 15);
    matrix.setRow(6, 15);
    break;
  case 22:
    matrix.setRow(1, 10);
    matrix.setRow(2, 15);
    matrix.setRow(3, 15);
    matrix.setRow(4, 15);
    matrix.setRow(5, 15);
    matrix.setRow(6, 15);
    break;
  case 23:
    matrix.setRow(1, 14);
    matrix.setRow(2, 15);
    matrix.setRow(3, 15);
    matrix.setRow(4, 15);
    matrix.setRow(5, 15);
    matrix.setRow(6, 15);
    break;
  case 24:
    matrix.setRow(1, 15);
    matrix.setRow(2, 15);
    matrix.setRow(3, 15);
    matrix.setRow(4, 15);
    matrix.setRow(5, 15);
    matrix.setRow(6, 15);
    break;
  case 25:
    matrix.setRow(0, 2);
    matrix.setRow(1, 15);
    matrix.setRow(2, 15);
    matrix.setRow(3, 15);
    matrix.setRow(4, 15);
    matrix.setRow(5, 15);
    matrix.setRow(6, 15);
    break;
  case 26:
    matrix.setRow(0, 10);
    matrix.setRow(1, 15);
    matrix.setRow(2, 15);
    matrix.setRow(3, 15);
    matrix.setRow(4, 15);
    matrix.setRow(5, 15);
    matrix.setRow(6, 15);
    break;
  case 27:
    matrix.setRow(0, 14);
    matrix.setRow(1, 15);
    matrix.setRow(2, 15);
    matrix.setRow(3, 15);
    matrix.setRow(4, 15);
    matrix.setRow(5, 15);
    matrix.setRow(6, 15);
    break;
  case 28:
    matrix.setRow(0, 15);
    matrix.setRow(1, 15);
    matrix.setRow(2, 15);
    matrix.setRow(3, 15);
    matrix.setRow(4, 15);
    matrix.setRow(5, 15);
    matrix.setRow(6, 15);
    break;
  case 29:
    matrix.setRow(0, 15);
    matrix.setRow(1, 15);
    matrix.setRow(2, 15);
    matrix.setRow(3, 15);
    matrix.setRow(4, 15);
    matrix.setRow(5, 15);
    matrix.setRow(6, 13);
    break;
  case 30:
    matrix.setRow(0, 15);
    matrix.setRow(1, 15);
    matrix.setRow(2, 15);
    matrix.setRow(3, 15);
    matrix.setRow(4, 15);
    matrix.setRow(5, 15);
    matrix.setRow(6, 5);
    break;
  case 31:
    matrix.setRow(0, 15);
    matrix.setRow(1, 15);
    matrix.setRow(2, 15);
    matrix.setRow(3, 15);
    matrix.setRow(4, 15);
    matrix.setRow(5, 15);
    matrix.setRow(6, 1);
    break;
    case 32:
    matrix.setRow(0, 15);
    matrix.setRow(1, 15);
    matrix.setRow(2, 15);
    matrix.setRow(3, 15);
    matrix.setRow(4, 15);
    matrix.setRow(5, 15);
    break;
    case 33:
    matrix.setRow(0, 15);
    matrix.setRow(1, 15);
    matrix.setRow(2, 15);
    matrix.setRow(3, 15);
    matrix.setRow(4, 15);
    matrix.setRow(5, 13);
    break;
    case 34:
    matrix.setRow(0, 15);
    matrix.setRow(1, 15);
    matrix.setRow(2, 15);
    matrix.setRow(3, 15);
    matrix.setRow(4, 15);
    matrix.setRow(5, 5);
    break;
    case 35:
    matrix.setRow(0, 15);
    matrix.setRow(1, 15);
    matrix.setRow(2, 15);
    matrix.setRow(3, 15);
    matrix.setRow(4, 15);
    matrix.setRow(5, 1);
    break;
    case 36:
    matrix.setRow(0, 15);
    matrix.setRow(1, 15);
    matrix.setRow(2, 15);
    matrix.setRow(3, 15);
    matrix.setRow(4, 15);
    break;
    case 37:
    matrix.setRow(0, 15);
    matrix.setRow(1, 15);
    matrix.setRow(2, 15);
    matrix.setRow(3, 15);
    matrix.setRow(4, 13);
    break;
    case 38:
    matrix.setRow(0, 15);
    matrix.setRow(1, 15);
    matrix.setRow(2, 15);
    matrix.setRow(3, 15);
    matrix.setRow(4, 5);
    break;
    case 39:
    matrix.setRow(0, 15);
    matrix.setRow(1, 15);
    matrix.setRow(2, 15);
    matrix.setRow(3, 15);
    matrix.setRow(4, 1);
    break;
    case 40:
    matrix.setRow(0, 15);
    matrix.setRow(1, 15);
    matrix.setRow(2, 15);
    matrix.setRow(3, 15);
    break;
    case 41:
    matrix.setRow(0, 15);
    matrix.setRow(1, 15);
    matrix.setRow(2, 15);
    matrix.setRow(3, 13);
    break;
    case 42:
    matrix.setRow(0, 15);
    matrix.setRow(1, 15);
    matrix.setRow(2, 15);
    matrix.setRow(3, 5);
    break;
    case 43:
    matrix.setRow(0, 15);
    matrix.setRow(1, 15);
    matrix.setRow(2, 15);
    matrix.setRow(3, 1);
    break;
    case 44:
    matrix.setRow(0, 15);
    matrix.setRow(1, 15);
    matrix.setRow(2, 15);
    break;
    case 45:
    matrix.setRow(0, 15);
    matrix.setRow(1, 15);
    matrix.setRow(2, 13);
    break;
    case 46:
    matrix.setRow(0, 15);
    matrix.setRow(1, 15);
    matrix.setRow(2, 5);
    break;
    case 47:
    matrix.setRow(0, 15);
    matrix.setRow(1, 15);
    matrix.setRow(2, 1);
    break;
    case 48:
    matrix.setRow(0, 15);
    matrix.setRow(1, 15);
    break;
    case 49:
    matrix.setRow(0, 15);
    matrix.setRow(1, 13);
    break;
    case 50:
    matrix.setRow(0, 15);
    matrix.setRow(1, 5);
    break;
    case 51:
    matrix.setRow(0, 15);
    matrix.setRow(1, 1);
    break;
    case 52:
    matrix.setRow(0, 15);
    break;
    case 53:
    matrix.setRow(0, 13);
    break;
    case 54:
    matrix.setRow(0, 5);
    break;
    case 55:
    matrix.setRow(0, 1);
    break;
    case 56:
    matrix.setRow(0, 0);
    state= cycle;
    break;
  default:
    // statements
    break;
}
}
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

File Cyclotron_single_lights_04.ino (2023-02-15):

// This code has initially been created entirelly by Arpehem and is free to be used, modified or updated by anyone as long as this credit remains.
// This code is compatible a smoker for the N-filter but is optional.

#include <DFPlayerMini_Fast.h>
#include <FastLED.h>
#include <SoftwareSerial.h>
#define POWERCELL_LED_PIN 3
#define CYCLOTRON_LED_PIN 2
# define CELL_LEDS 16
# define Cyclotron_LEDS 4
# define NUM_LEDS 20
# define NUM_STRIPS 2

int i =0;
int V = 90;
int y = 16;
int powercell_min = 0;
int powecell_cycle = -1;
int powercell = 0;
int cyclotron = 0;
int cyclotron_reset = 0;
int Volume=20;
int smokepin=5;
int purgepin=4;
int red = 255;
bool dim;
bool alarmbool=false;
bool smoking = false;
bool smoke = false;
bool bootnew = true;
bool justvent = false;
int dim_count;
float gBrightness = 5;
unsigned long myTime;
unsigned long previousMyTime = 0;
unsigned long previousdimTime = 0;
CRGB cell_leds[CELL_LEDS]; // Powercell LED array
CRGB cyclo_leds[Cyclotron_LEDS];
CLEDController *controllers[NUM_STRIPS]; // Controller array
enum currentstate{off,boot,cycle,fire,overloading,overload,overheat,music,volumep,ventp}state;
char message;
bool booted=false;

SoftwareSerial mySerial(11, 10); // RX, TX
DFPlayerMini_Fast myMP3;

void setup() {
  Serial.begin(9600);
mySerial.begin(9600);
myMP3.begin(mySerial, true);
pinMode(smokepin, OUTPUT);
pinMode(purgepin, OUTPUT);
digitalWrite(smokepin, LOW);
digitalWrite(purgepin, LOW);
  controllers[0] = &FastLED.addLeds<WS2812, POWERCELL_LED_PIN, GRB>(cell_leds, CELL_LEDS); // Assign Powercell LED to controller 0
  controllers[1] = &FastLED.addLeds<WS2812, CYCLOTRON_LED_PIN, RGB>(cyclo_leds, Cyclotron_LEDS); // Assign Cyclotron LED to controller 1
  FastLED.setMaxPowerInVoltsAndMilliamps(5,500);
  FastLED.clear();
  FastLED.show();
FastLED.setBrightness(75);
myMP3.volume(Volume);

}
void loop() {
    myTime = millis();

  if(Serial.available()){
    message=Serial.read();

  if(isAlpha(message)){
    messageswitch(message);

  }
else{
    if(state==volumep){
          Volume=message;
    myMP3.volume(Volume);
    }
    else{
      int translator=message;
      
      V=max(map(translator,1,35,0,90),15);
    }

    

}
  }
  if (myTime > previousMyTime+90+20&&booted==true&&state==overheat){
    alarm();
        if (smoke==true){
digitalWrite(smokepin, HIGH);
  }
    
    smoking=true;

  }
  if (myTime > previousMyTime+90+20&&booted==true&&state==overload){
    alarm();
    
  }
  if (myTime > previousMyTime+V&&booted==true&&state!=overload&&state!=overheat){
    cyclesequence();
     
  }

//debug();

}
void messageswitch(char var){
  switch (var) {
      case 'x':
    smoke=false;
    break;
      case 'y':
    smoke=true;
    break;
  case 'b':
    bootsequence();
    break;
  case 'f':
  if (state!=off){
        shutdownsequence();        
        }
    
    break;
      case 'm':
      if (state!=music){
        myMP3.repeatFolder(2);          
        state=music;
      }
      else{
        state=cycle;
        loopsound(2);
      }

    break;
          case 'n':
         myMP3.playNext();

    break;
          case 's':
      if(state!=fire){
        state=fire;
        loopsound(11);
      }
    break;
              case 'c':
      if(state!=cycle&&state!=music&&state!=volumep){
        state=cycle;
        loopsound(2);
         }
    break;
    case 'h':
      if(state!=overheat){
        state=overheat;
        loopsound(16);
       
         }
    break;
        case 'o':
      if(state!=overload){
        state=overload;
        
         }
    break;
            case 'v':
      if(state!=ventp){
        state=ventp;
        vent();
        loopsound(2);
        
         }
    break;
    case 'V':
      if(state!=volumep){
        state=volumep;
        advertise(8);
      }
  default:
    // statements
    break;
}
}
void vent(){
  if (smoking==false&&smoke==true){
    digitalWrite(smokepin, HIGH);
    delay(500);
  }
  playsound(9);
    if (smoke==true){
digitalWrite(purgepin, HIGH);
  }

  gBrightness=255;
  FastLED.clear();
  FastLED.show();
  for(y=0;y<16;y++){
    cell_leds[y] = CRGB(0,0,255);
    controllers[0]->showLeds(gBrightness);
  }
    for(y=0;y<4;y++){
    cyclo_leds[y] = CRGB(255,0,0);
    controllers[1]->showLeds(gBrightness);
  }

//  for (y=0;y<34;y++){
//    gBrightness=gBrightness-8;
//    cell_leds[max(15-y/2,0)] = CRGB(0,0,0);
//    controllers[0]->showLeds(75);
//    controllers[1]->showLeds(max(gBrightness,0));
//    delay(100);
//  }
delay(750);
int blue = 255;
for(cyclotron=0;cyclotron<4;cyclotron++){
  red=255;
  
for(int cl=0;cl<64;cl++){
  red=max(red-10,0);
  cyclo_leds[cyclotron] = CRGB(red,0,0);
 controllers[1]->showLeds(gBrightness);
 controllers[0]->showLeds(blue);
 blue=max(blue-1,0);
 delay(10);
}
//delay(10);
if(red==0){
  red=255;
}
}
justvent=true;
 i =0;
 V = 90;
 y = 16;
 powercell_min = 0;
 powecell_cycle = -1;
 powercell = 0;
 cyclotron = 0;
 cyclotron_reset = 0;
    FastLED.clear();
  FastLED.show();
  purge_powercell();
  previousMyTime = myTime;
  digitalWrite(smokepin, LOW);
  smoking = false;
  digitalWrite(purgepin, LOW);
  state=cycle;
  loopsound(2);
  
}
void alarm(){

    gBrightness=175;
  if(alarmbool==false){
    FastLED.clear();
      for (y=0;y<9;y++){
    cell_leds[y*2] = CRGB(0,0,255);
    alarmbool=true;
    controllers[0]->showLeds(gBrightness);
    
    
  }
      for (int z=0;z<4;z++){
      cyclo_leds[z] = CRGB(255,0,0);
      controllers[1]->showLeds(gBrightness);
    }
  }
else{
  FastLED.clear();
    for (y=1;y<9;y++){
    cell_leds[y*2-1] = CRGB(0,0,255);
    cyclo_leds[Cyclotron_LEDS] = CRGB(0,0,0);
    alarmbool=false;
    controllers[0]->showLeds(gBrightness);
    controllers[1]->showLeds(0);
    }
  for (int z=0;z<4;z++){
      cyclo_leds[z] = CRGB(0,0,0);
      controllers[1]->showLeds(0);
    }  
  }
  FastLED.show();
  previousMyTime = myTime;

}
void playsound(int sound){
    mySerial.begin(9600);
 // delay(50);
  myMP3.play(sound); 
  delay(50);
    Serial.begin(9600);
 
}
void advertise(int sound){
    mySerial.begin(9600);
 // delay(50);
  myMP3.playAdvertisement(sound); 
  delay(50);
    Serial.begin(9600);
 
}
void bootsequence(){
  bootnew=true;
 // Serial.print("boot");
 // Serial.println();
 playsound(1);
  for(int b=0; b<15;b++){
    for (int L=0; L<4;L++){
      cyclo_leds[L] = CRGB(255,0,0);
    }
 
for (int y=15; y>=powercell_min;y--){
  cell_leds[y] = CRGB(0,0,255);
 gBrightness=pow(gBrightness,1.008);
 gBrightness=min(gBrightness,150);
  controllers[0]->showLeds(max(gBrightness,75));
  controllers[1]->showLeds(min(gBrightness,225));
  cell_leds[min(y+1,15)] = CRGB(0,0,0);
  delay(25);
  }
  powercell_min++;
  }
  purge_powercell();
  for(int Z=0; Z<28;Z++){
cyclo_leds[Z] = CRGB(0,0,0);
}
    booted=true;
     state=cycle;
        loopsound(2);

  }
  void shutdownsequence(){
playsound(10);
gBrightness=200;
for(int y=15; y>0 ; y--){
  cell_leds[y] = CRGB(0,0,255);
}
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
